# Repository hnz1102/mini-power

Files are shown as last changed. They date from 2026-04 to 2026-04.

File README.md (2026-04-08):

<div align="center">
  <h1><code>Mini Power for Breadboard</code></h1>
  <p>
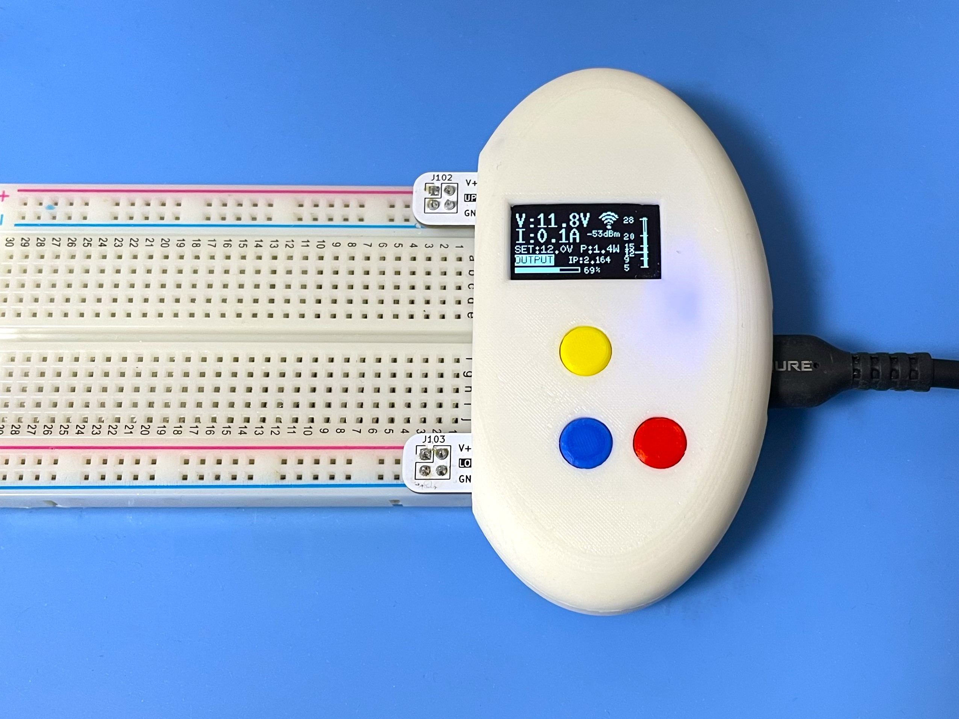
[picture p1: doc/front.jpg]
    
  </p>
</div>

# Mini-Power

Mini-Power is a small, portable DC power supply unit designed to provide a convenient and reliable source of adjustable voltage for your electronic devices and breadboard experiments. Powered from a USB Power Delivery (PD) charger, it supports both Standard Power Range (SPR) and Extended Power Range (EPR) modes, making it perfect for electronics developers, students, and anyone who needs a compact bench power supply.

## Key Features

- **Easy access to the breadboard**: both sides accessible via standard 2.54mm pitch pin headers.
- **USB PD support**: 5V to 28V output using the AP33772S PD Sink Controller.
- **Variable voltage**: 0.1V steps using PPS APDO, with automatic fallback to the nearest Fixed PDO.
- **Real-time display**: SSD1306 128×64 OLED showing output voltage, measured voltage, current, power, WiFi status, and buffer usage.
- **Data logging**: Measurements sent to InfluxDB over WiFi (InfluxDB Line Protocol, HTTPS).
- **Remote syslog**: RFC 5424 over UDP for monitoring and troubleshooting.
- **HTTP web interface**: Real-time graphs (Chart.js), voltage control, and output ON/OFF toggle from any browser on the local network.
- **Three-button interface**: Up / Down / Center push buttons for direct voltage adjustment and output control.
- **NVS persistence**: Last voltage setting is saved to flash and restored on reboot.
- **Safety protections**: OVP, UVP, OCP (in AP33772S hardware) plus software current/power limits and voltage overshoot detection (>110% of setpoint).

## Hardware Components

| Reference | Part | Description |
|---|---|---|
| U103 | ESP32-C3-WROOM-02-N4 | Main microcontroller (RISC-V, built-in WiFi, 4MB flash) |
| U104 | AP33772SDKZ-13-FA01 | USB Power Delivery Sink Controller (SPR + EPR), QFN4040-24 |
| U102 | SSD1306 | Monochrome OLED display (128×64 pixels, I2C) |
| U101 | PCA9306D | Dual bidirectional I2C voltage-level translator (SSOP-8) |
| U105 | NJW1933F1 | Synchronous step-down DC/DC converter for 3.3V supply (SOT-23-6) |
| Q101, Q102 | DMN3008SFG | Dual N-channel MOSFET for output switching (PowerDI3333-8) |
| J101 | USB4105-GF-A | USB Type-C connector (input) |
| J102, J103 | 2×2 pin header | Output terminals (UPPER OUT / LOWER OUT), 2.54mm pitch |
| SW101–SW103 | TS-06104 | Push buttons: Up (GPIO10), Down (GPIO20), Center (GPIO21) |
| R110 | 5mΩ shunt resistor | Current sensing resistor (2512 package) |
| L101 | 22µH | Inductor for DC/DC converter |
| D101 | LED (Blue) | Status indicator |
| D102 | SK36A-LTP | Schottky diode (SMA) |
| FB101 | MH2029-601Y | Ferrite bead for EMI filtering |

Schematic and PCB files are in the `hardware/` directory. The board is designed with [KiCad](https://www.kicad.org/). A PDF export of the schematic is available at [`hardware/schematic.pdf`](hardware/schematic.pdf).

The [ap33772s-driver](https://github.com/hnz1102/ap33772s-driver) crate is used for all USB-PD communication with the AP33772S controller.

## Software Architecture

The firmware is written entirely in Rust using the ESP-IDF framework.

| File | Responsibility |
|---|---|
| `main.rs` | Startup, peripheral init, NVS load/save, main control loop |
| `usbpd.rs` | AP33772S PD driver wrapper (PDO negotiation, custom voltage request, VOUT control) |
| `displayctl.rs` | SSD1306 OLED driver, display thread, PDO list screen |
| `currentlogs.rs` | In-memory ring buffer (up to 127 records) for voltage/current/power/temp data |
| `transfer.rs` | InfluxDB Line Protocol HTTP transfer thread |
| `httpserver.rs` | HTTP server, REST API (`/api/status`, `/api/voltage`, `/api/output`, `/api/pdos`), embedded HTML/JS |
| `keyevent.rs` | GPIO key scanner (10ms polling, 100ms guard time) with long-press detection |
| `wifi.rs` | WiFi connection, RSSI monitoring, automatic reconnect |
| `syslogger.rs` | RFC 5424 UDP syslog, replaces the default ESP console logger |

## How to Use the Unit

### Basic Operation

1. **Connection**: Connect a USB-C PD charger*1 to the input port.
2. **Power On**: The unit negotiates PD profiles and scrolls through the available PDO list on the display.
3. **Main Screen**: After getting a IP address from DHCP server*2, the display shows output voltage, current, power, WiFi RSSI, IP address(last two octets)and buffer usage. 
4. **Voltage Selection**: Press **Up(yellow)** or **Down(blue)** to increase/decrease the target voltage in 0.1V steps.
5. **Output Control**: Press **Center(red)** to toggle output ON/OFF.
6. **Monitoring**: View real-time measurements on the OLED display or open `http://<device-ip>/` in a browser.

**Note** 
*1: When it doesn't connect to the PD charger, the display will show "No PD Power". Click the up/down buttons to show main screen. It only can output 5V.
*2: If it can't connect to WiFi, the display will show the main screen after 30 seconds, but without IP address and RSSI. 

### Button Controls

| Button | GPIO | Function |
|---|---|---|
| Up | GPIO10 | Increase output voltage by 0.1V |
| Down | GPIO20 | Decrease output voltage by 0.1V |
| Center | GPIO21 | Toggle output ON/OFF |

### OLED Display

The SSD1306 128×64 monochrome OLED display is divided into several regions as shown below.

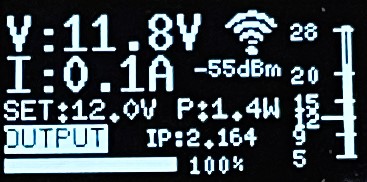
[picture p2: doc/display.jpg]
display layout


| Area | Content | Detail |
|---|---|---|
| `V:xx.xV` | Measured voltage | Read from AP33772S (updated every 100ms when output ON) |
| `I:xx.xA` | Measured current | Read from AP33772S (updated every 100ms when output ON) |
| `SET:xx.xV` | Target output voltage | Blinks while PD voltage negotiation is in progress |
| `P:xx.xW` / `P:xx.xmW` | Measured power | Auto-range: switches between mW and W (threshold 0.5W / 1.0W) |
| `OUTPUT` / `STOPPED` | Output state | `OUTPUT` shown inverted (white on black) when output is ON |
| IP address | Last two octets of device IP | e.g. `IP:2.142` for `192.168.2.142` |
| Buffer bar | InfluxDB send buffer usage | 60px wide bar; fills left-to-right as records accumulate (max 127) |
| `xxx%` | Buffer usage percentage | Displayed to the right of the buffer bar |
| WiFi icon | WiFi signal strength | 5-level icon (wifi-0 to wifi-4) based on RSSI; animated while connecting |
| `+xx dBm` | RSSI value | Shown below WiFi icon when connected |
| Voltage bar (right edge) | PDO voltage range | Vertical bar showing min–max PD voltage; Variable/PPS range filled, Fixed PDO voltages marked as horizontal lines; current SET voltage shown as a longer line marker |

**Startup sequence:**

1. At boot, the PDO list screen is shown first — all Power Data Objects negotiated with the charger are listed (voltage, current, max power, type). Each page is shown for 3 seconds.
2. After PDO display completes, the main screen appears.
3. Error / warning messages (e.g. `Voltage Overshoot`, `Current OV x.xxxA`) replace the main screen temporarily and auto-dismiss after 3 seconds.

### HTTP Web Interface

When connected to WiFi, open `http://<device-ip>/` (IP shown on OLED display) to access:

- Live voltage, current, and power readings updated every second
- Real-time voltage and current graph (Chart.js)
- PDO table showing all available power profiles from the charger
- Voltage control with +/− buttons (0.1V step)
- Output ON/OFF toggle

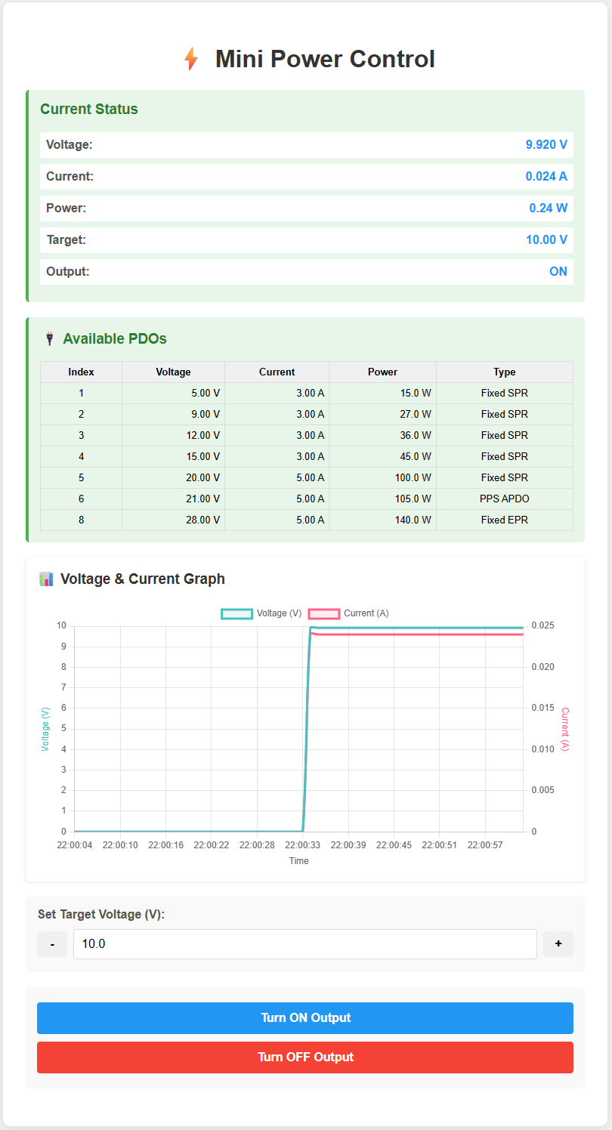
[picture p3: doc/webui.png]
webui


### Safety Protections

| Protection | Mechanism |
|---|---|
| Over Voltage Protection (OVP) | AP33772S hardware |
| Under Voltage Protection (UVP) | AP33772S hardware |
| Over Current Protection (OCP) | AP33772S hardware |
| Software current limit | Output disabled if current exceeds `max_current_limit` |
| Software power limit | Output disabled if power exceeds `max_power_limit` |
| Voltage overshoot detection | Output disabled if measured voltage > 110% of setpoint |

## How to Build from Code and Install to the Unit

### Using Ubuntu 22.04 LTS

**1. Install Rust Compiler**

```bash
sudo apt update && sudo apt -y install git python3 python3-pip gcc build-essential \
  curl pkg-config libudev-dev libtinfo5 clang libclang-dev llvm-dev udev libssl-dev python3.10-venv nano
```
```bash
curl --proto '=https' --tlsv1.2 -sSf https://sh.rustup.rs | sh
# Select option 1 (default install)
```
```bash
source "$HOME/.cargo/env"
```

**2. Install toolchain for ESP32-C3**

```bash
cargo install ldproxy
cargo install cargo-binstall
cargo install espup
espup install
espup update
. ./export-esp.sh
cargo binstall cargo-espflash
```

**3. Add UDEV rules**

```bash
sudo sh -c 'echo "SUBSYSTEMS==\"usb\", ATTRS{idVendor}==\"303a\", ATTRS{idProduct}==\"1001\", MODE=\"0666\"" \
  > /etc/udev/rules.d/99-esp32.rules'
sudo udevadm control --reload-rules
sudo udevadm trigger
```

**4. Clone the repository**

```bash
git clone https://github.com/hnz1102/mini-power.git
cd mini-power/code
```

**5. Configure WiFi and InfluxDB**

```bash
cp cfg.toml.samp cfg.toml
nano cfg.toml
```

```toml
[mini-power]
wifi_ssid = "YOUR_WIFI_SSID"
wifi_psk = "YOUR_WIFI_PASSWORD"
influxdb_server = "192.168.x.x:8086"
influxdb_api_key = "<YOUR_API_KEY>"
influxdb_api = "/api/v2/write?org=<ORG>&bucket=LOGGER&precision=ns"
influxdb_measurement = "minipower"
influxdb_tag = "ch"
max_current_limit = "5.2"
max_power_limit = "100.0"
max_temperature = "75"
syslog_server = "192.168.x.x:514"
syslog_enable = "false"
```

**6. Connect the board and verify**

```bash
cargo espflash board-info
# Select /dev/ttyACM0
# Expected: Chip type: esp32c3, Flash size: 4MB
```

**7. Build and flash**

```bash
cargo espflash flash --release --monitor
```

The device boots automatically after flashing. The OLED display will show the PDO list negotiated with the charger, then switch to the main monitoring screen.

## How to Install InfluxDB and Configure the Dashboard

**1. Download and install InfluxDB**

```bash
wget https://dl.influxdata.com/influxdb/releases/influxdb2-2.7.0-amd64.deb
sudo dpkg -i influxdb2-2.7.0-amd64.deb
sudo service influxdb start
```

**2. Initial configuration**

Open `http://<server-ip>:8086`. Click `GET STARTED` and set:

| Term | Value |
|---|---|
| Username | Admin login username |
| Password | Admin login password |
| Initial Organization Name | e.g. `ORG` |
| Initial Bucket Name | `LOGGER` |

**3. Get the API Token**

Copy the Operator API Token shown after setup — you will not see it again. To generate a new token later: `API Tokens` → `GENERATE API TOKEN` → `All access token`.

**4. Import the Dashboard Template**

Click `Dashboard` → `CREATE DASHBOARD` → `Import Dashboard`. Drop the `influxdb/mimi-power.json` file into the import dialog, then click `IMPORT JSON AS DASHBOARD`.

You will see the **Mimi-POWER** dashboard. It contains three time-series graphs:

| Chart | Field | Unit |
|---|---|---|
| Voltage | `voltage` | V |
| Current | `current` | A |
| Power | `power` | W |

All charts query the `LOGGER` bucket, measurement `minipower`, tag `tag = "ch"`.

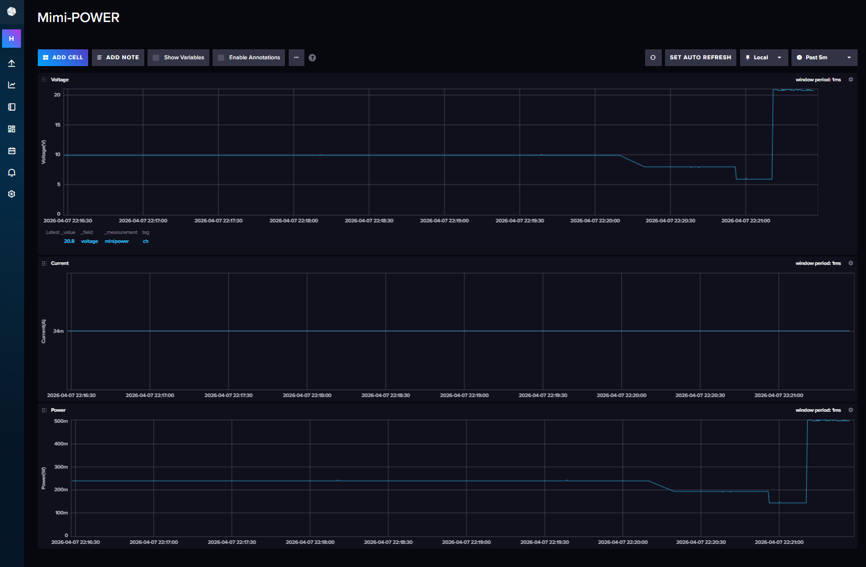
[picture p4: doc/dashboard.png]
dashboard


**5. Start logging**

Enable the output on the Mini-Power unit (Center button or web interface). Measurement data will be sent to InfluxDB and appear on the dashboard in real-time.

## Schematic and PCB Data

The PCB is designed with [KiCad](https://www.kicad.org/). All hardware design files are in the `hardware/` directory.

| File / Directory | Description |
|---|---|
| [`hardware/schematic.pdf`](hardware/schematic.pdf) | Schematic PDF (for viewing without KiCad) |
| `hardware/mini-power.kicad_sch` | KiCad schematic source |
| `hardware/mini-power.kicad_pcb` | KiCad PCB layout |
| `hardware/bom.csv` | Bill of Materials |
| `hardware/production/` | Gerber files for PCB manufacturing (`mini-power.kicad_pcb_gerber.zip`) |

## 3D Printed Enclosure

The enclosure design files are in the `hardware/Container/` directory.

| File | Description |
|---|---|
| `body.3mf` | Main enclosure body |
| `upper.3mf` | Top cover |
| `button.3mf` | Button cap for the three push switches |
| `mini-power.f3d` | Fusion 360 source file |

All parts are designed for FDM 3D printing. Print `body.3mf`, `upper.3mf`, and three copies of `button.3mf`.

## License

This source code is licensed under MIT. Other Hardware Schematic documents are licensed under CC-BY-SA V4.0.

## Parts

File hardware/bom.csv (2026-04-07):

Reference | Qty | Value | DNP | Exclude from BOM | Exclude from Board | Footprint | Datasheet | digikey
C101,C110 | 2 | 1uF |  |  |  | Capacitor_SMD:C_0805_2012Metric | ~ | 311-1365-1-ND
C102,C103,C105,C106,C108 | 5 | 0.1uF/50V |  |  |  | Capacitor_SMD:C_0603_1608Metric | ~ | 311-1343-1-ND
C104,C111 | 2 | 10uF/50V |  |  |  | Capacitor_SMD:C_0805_2012Metric | ~ | 490-18663-1-ND
C107 | 1 | 0.01uF/50V |  |  |  | Capacitor_SMD:C_0603_1608Metric | ~ | 311-1349-1-ND
C109 | 1 | 2.2uF/50V |  |  |  | Capacitor_SMD:C_0603_1608Metric | ~ | 587-4320-1-ND
C112 | 1 | 47uF |  |  |  | Capacitor_SMD:C_0805_2012Metric | ~ | 587-4280-1-ND
D101 | 1 | LED BLUE |  |  |  | LED_SMD:LED_0603_1608Metric | ~ | 3147-B1931NB--20C007614U1930CT-ND
D102 | 1 | SK36A-LTP |  |  |  | Diode_SMD:D_SMA |  | SK36A-LTPMSCT-ND
FB101 | 1 | MH2029-601Y |  |  |  | Inductor_SMD:L_0805_2012Metric | ~ | MH2029-601YCT-ND
J101 | 1 | USB4105-GF-A |  |  |  | Library:USB_C_5077CR-16-SMC2-BK-TR | https://www.usb.org/sites/default/files/documents/usb_type-c.zip | 2073-USB4105-GF-ACT-ND
J102 | 1 | UPPER OUT |  |  |  | Connector_PinHeader_2.54mm:PinHeader_2x02_P2.54mm_Vertical | ~ | 2057-PH2-04-UA-ND
J103 | 1 | LOWER OUT |  |  |  | Connector_PinHeader_2.54mm:PinHeader_2x02_P2.54mm_Vertical | ~ | 2057-PH2-04-UA-ND
JP101 | 1 | SolderJumper_2_Open |  |  |  | Jumper:SolderJumper-2_P1.3mm_Open_RoundedPad1.0x1.5mm | ~ | -
L101 | 1 | 22uH |  |  |  | Library:L_CHPH4D19FNP | ~ | 308-1313-1-ND
Q101,Q102 | 2 | DMN3008SFG |  |  |  | Package_SON:Diodes_PowerDI3333-8 | https://www.diodes.com/assets/Datasheets/DMN3008SFG.pdf | DMN3008SFG-7DICT-ND
R101,R105,R107,R111,R117,R118,R119,R120 | 8 | 10K |  |  |  | Resistor_SMD:R_0603_1608Metric | ~ | 311-10.0KHRCT-ND
R102 | 1 | 200K |  |  |  | Resistor_SMD:R_0603_1608Metric | ~ | 311-200KHRCT-ND
R103,R104,R116 | 3 | 5K1 |  |  |  | Resistor_SMD:R_0603_1608Metric | ~ | 311-5.10KHRCT-ND
R106 | 1 | 1K |  |  |  | Resistor_SMD:R_0603_1608Metric | ~ | RMCF0603FT1K00CT-ND
R108,R109 | 2 | 4.7K |  |  |  | Resistor_SMD:R_0603_1608Metric | ~ | 311-4.70KHRCT-ND
R110 | 1 | 5m |  |  |  | Resistor_SMD:R_2512_6332Metric_Pad1.40x3.35mm_HandSolder | ~ | 4506-PEWF2512D5L00Q9CT-ND
R112 | 1 | 100R |  |  |  | Resistor_SMD:R_0603_1608Metric | ~ | 311-10.0HRCT-ND
R114 | 1 | 100 |  |  |  | Resistor_SMD:R_0603_1608Metric | ~ | 311-100GRCT-ND
R115 | 1 | 3K09 |  |  |  | Resistor_SMD:R_0603_1608Metric | ~ | 311-3.09KHRCT-ND
SW101,SW102,SW103 | 3 | TS-06104 |  |  |  | Library:TS-06104 |  | C2939203 JLPCB Part#
TP101 | 1 | 5V |  |  |  | TestPoint:TestPoint_Pad_D1.0mm | ~ | -
TP102 | 1 | VDD |  |  |  | TestPoint:TestPoint_Pad_D1.0mm | ~ | -
TP103 | 1 | 3V3 |  |  |  | TestPoint:TestPoint_Pad_D1.0mm | ~ | -
U101 | 1 | PCA9306D |  |  |  | Package_SO:SSOP-8_2.95x2.8mm_P0.65mm | https://www.nxp.com/docs/en/data-sheet/PCA9306.pdf | 568-4215-1-ND
U102 | 1 | SSD1306_DISPLAY |  |  |  | Library:OLED I2C DISPLAY |  | https://akizukidenshi.com/catalog/g/g112031/
U103 | 1 | ESP32-C3-WROOM-02-N4 |  |  |  | Library:IC18_ESP32-C3-WROOM-02-N4_EXP | ESP32-C3-WROOM-02-N4 | 1965-ESP32-C3-WROOM-02-N4CT-ND
U104 | 1 | AP33772SDKZ-13-FA01 |  |  |  | Library:W-QFN4040-24_Type_A1_DIO | AP33772SDKZ-13 | 31-AP33772SDKZ-13-FA01CT-ND
U105 | 1 | NJW1933F1 |  |  |  | Package_TO_SOT_SMD:SOT-23-6

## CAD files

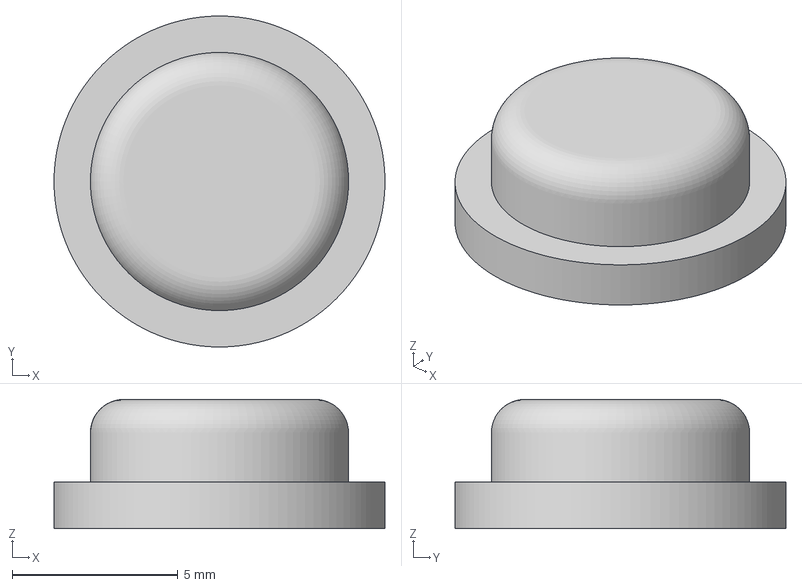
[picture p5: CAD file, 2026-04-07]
hardware/Container/button.3mf
10.0 x 10.0 x 3.90 mm

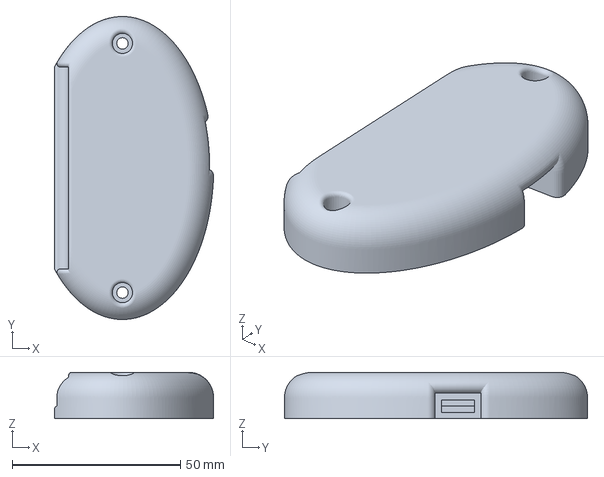
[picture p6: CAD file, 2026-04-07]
hardware/Container/body.3mf
47.3 x 90.0 x 13.8 mm

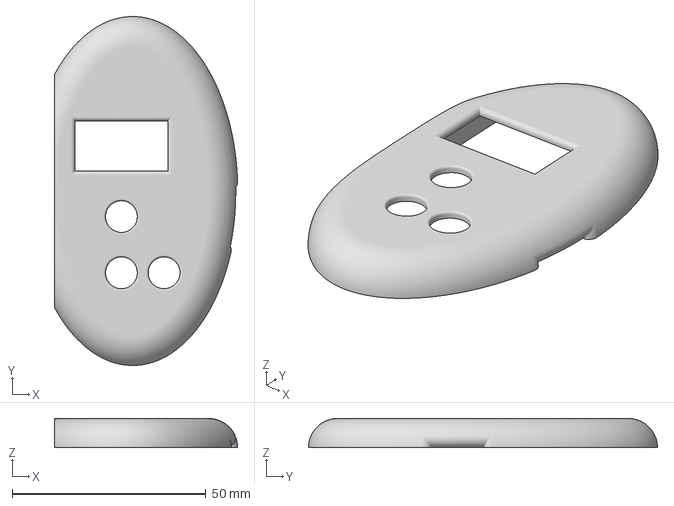
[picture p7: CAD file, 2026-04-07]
hardware/Container/upper.3mf
47.3 x 90.0 x 7.50 mm

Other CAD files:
hardware/Container/mini-power.f3d

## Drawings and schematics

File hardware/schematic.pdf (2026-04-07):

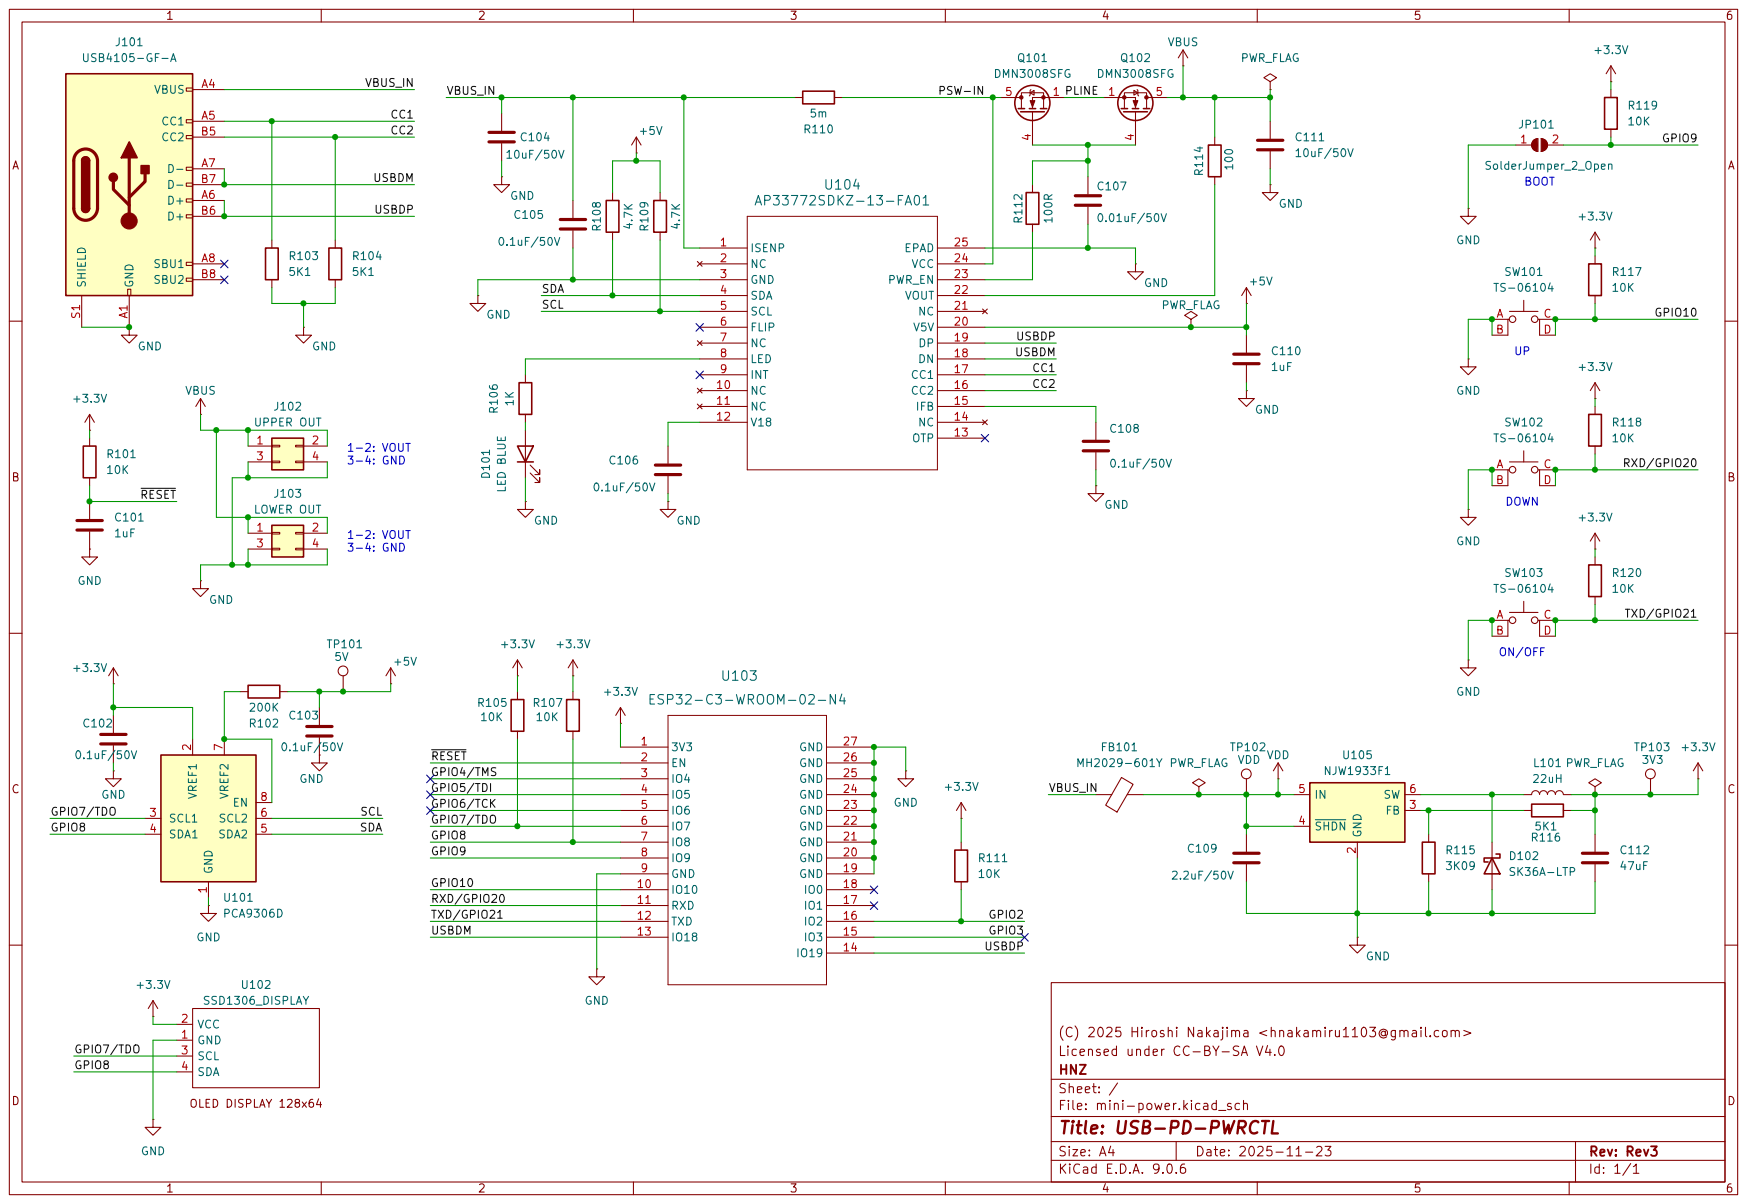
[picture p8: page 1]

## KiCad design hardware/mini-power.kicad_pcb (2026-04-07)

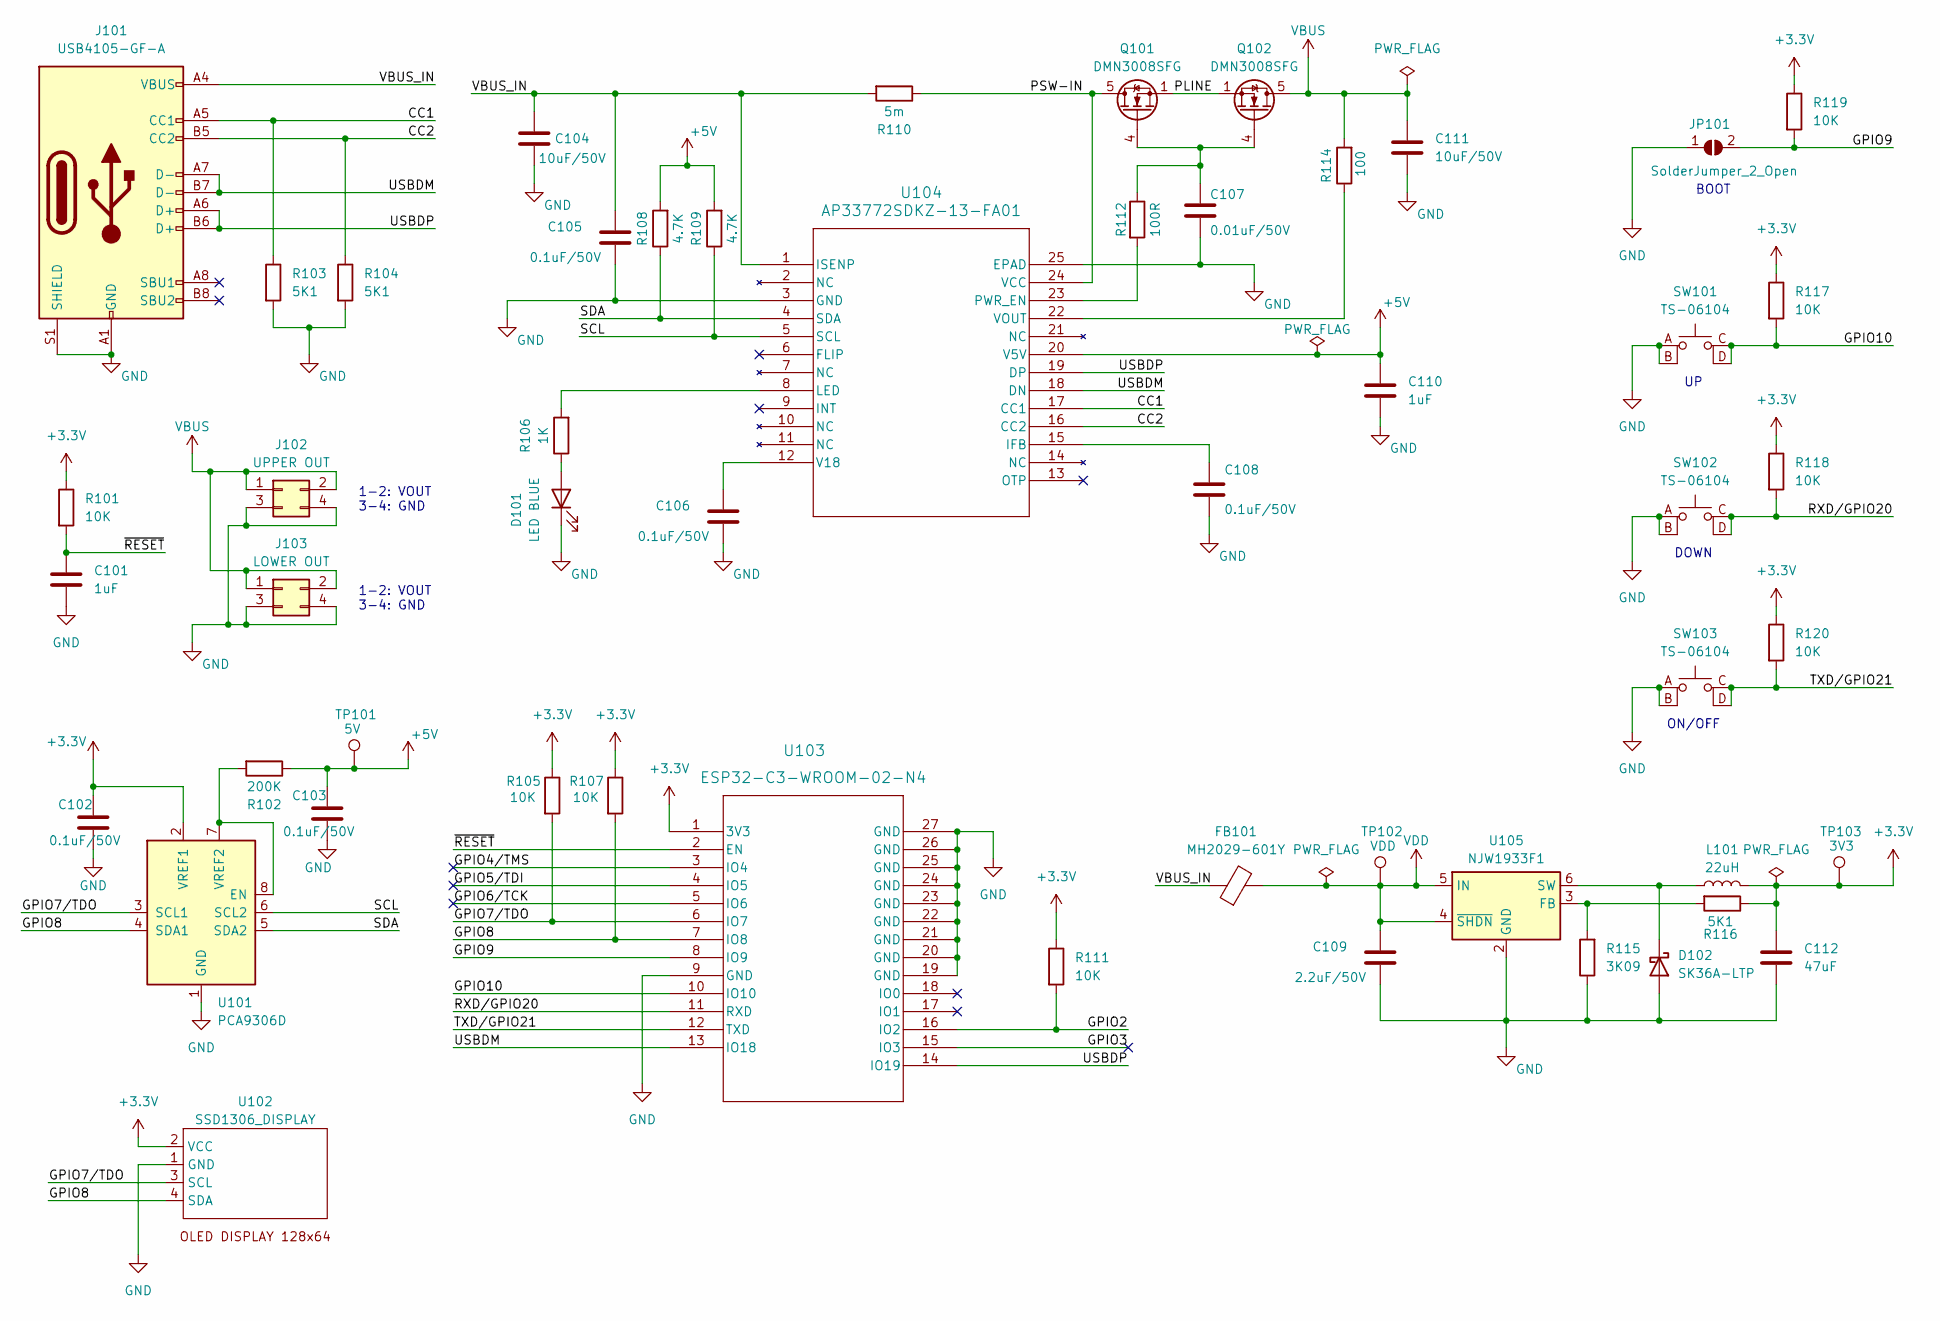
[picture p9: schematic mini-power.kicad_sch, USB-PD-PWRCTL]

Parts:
C101, C110: 1uF; C_0805_2012Metric; digikey 311-1365-1-ND
C102, C103, C105, C106, C108: 0.1uF/50V; C_0603_1608Metric; digikey 311-1343-1-ND
C104, C111: 10uF/50V; C_0805_2012Metric; digikey 490-18663-1-ND
C107: 0.01uF/50V; C_0603_1608Metric; digikey 311-1349-1-ND
C109: 2.2uF/50V; C_0603_1608Metric; digikey 587-4320-1-ND
C112: 47uF; C_0805_2012Metric; digikey 587-4280-1-ND
D101: LED BLUE; LED_0603_1608Metric; digikey 3147-B1931NB--20C007614U1930CT-ND
D102: SK36A-LTP; D_SMA; digikey SK36A-LTPMSCT-ND
FB101: MH2029-601Y; L_0805_2012Metric; digikey MH2029-601YCT-ND
J101: USB4105-GF-A; USB_C_5077CR-16-SMC2-BK-TR; digikey 2073-USB4105-GF-ACT-ND
J102: UPPER OUT; PinHeader_2x02_P2.54mm_Vertical; digikey 2057-PH2-04-UA-ND
J103: LOWER OUT; PinHeader_2x02_P2.54mm_Vertical; digikey 2057-PH2-04-UA-ND
JP101: SolderJumper_2_Open; SolderJumper-2_P1.3mm_Open_RoundedPad1.0x1.5mm
L101: 22uH; L_CHPH4D19FNP; digikey 308-1313-1-ND
Q101, Q102: DMN3008SFG; Diodes_PowerDI3333-8; digikey DMN3008SFG-7DICT-ND
R101, R105, R107, R111, R117, R118, R119, R120: 10K; R_0603_1608Metric; digikey 311-10.0KHRCT-ND
R102: 200K; R_0603_1608Metric; digikey 311-200KHRCT-ND
R103, R104, R116: 5K1; R_0603_1608Metric; digikey 311-5.10KHRCT-ND
R106: 1K; R_0603_1608Metric; digikey RMCF0603FT1K00CT-ND
R108, R109: 4.7K; R_0603_1608Metric; digikey 311-4.70KHRCT-ND
R110: 5m; R_2512_6332Metric_Pad1.40x3.35mm_HandSolder; digikey 4506-PEWF2512D5L00Q9CT-ND
R112: 100R; R_0603_1608Metric; digikey 311-10.0HRCT-ND
R114: 100; R_0603_1608Metric; digikey 311-100GRCT-ND
R115: 3K09; R_0603_1608Metric; digikey 311-3.09KHRCT-ND
SW101, SW102, SW103: TS-06104; digikey C2939203 JLPCB Part#
TP101: 5V; TestPoint_Pad_D1.0mm
TP102: VDD; TestPoint_Pad_D1.0mm
TP103: 3V3; TestPoint_Pad_D1.0mm
U101: PCA9306D; SSOP-8_2.95x2.8mm_P0.65mm; digikey 568-4215-1-ND
U102: SSD1306_DISPLAY; OLED I2C DISPLAY
U103: ESP32-C3-WROOM-02-N4; IC18_ESP32-C3-WROOM-02-N4_EXP; digikey 1965-ESP32-C3-WROOM-02-N4CT-ND
U104: AP33772SDKZ-13-FA01; W-QFN4040-24_Type_A1_DIO; digikey 31-AP33772SDKZ-13-FA01CT-ND
U105: NJW1933F1; SOT-23-6

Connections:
+3.3V: C102.1, C112.1, L101.2, R101.1, R105.1, R107.1, R111.1, R116.1, R117.1, R118.1, R119.1, R120.1, TP103.1, U101.2 (VREF1), U102.2 (VCC), U103.1 (3V3)
+5V: C103.1, C110.1, R102.1, R108.2, R109.2, TP101.1, U104.20 (V5V)
/CC1: J101.A5 (CC1), R103.1, U104.17 (CC1)
/CC2: J101.B5 (CC2), R104.1, U104.16 (CC2)
/GPIO2: R111.2, U103.16 (IO2)
/GPIO3: U103.15 (IO3)
/GPIO4/TMS: U103.3 (IO4)
/GPIO5/TDI: U103.4 (IO5)
/GPIO6/TCK: U103.5 (IO6)
/GPIO7/TDO: R105.2, U101.3 (SCL1), U102.3 (SCL), U103.6 (IO7)
/GPIO8: R107.2, U101.4 (SDA1), U102.4 (SDA), U103.7 (IO8)
/GPIO9: JP101.2 (B), R119.2, U103.8 (IO9)
/GPIO10: R117.2, SW101.C, SW101.D, U103.10 (IO10)
/PLINE: Q101.1 (S), Q101.2 (S), Q101.3 (S), Q102.1 (S), Q102.2 (S), Q102.3 (S)
/PSW-IN: Q101.5 (D), R110.1, U104.24 (VCC)
/RXD/GPIO20: R118.2, SW102.C, SW102.D, U103.11 (RXD)
/SCL: R109.1, U101.6 (SCL2), U104.5 (SCL)
/SDA: R108.1, U101.5 (SDA2), U104.4 (SDA)
/TXD/GPIO21: R120.2, SW103.C, SW103.D, U103.12 (TXD)
/USBDM: J101.A7 (D-), J101.B7 (D-), U103.13 (IO18), U104.18 (DN)
/USBDP: J101.A6 (D+), J101.B6 (D+), U103.14 (IO19), U104.19 (DP)
/VBUS_IN: C104.1, C105.1, FB101.1, J101.A4 (VBUS), J101.A9 (VBUS), J101.B4 (VBUS), J101.B9 (VBUS), R110.2, U104.1 (ISENP)
/~RESET: C101.1, R101.2, U103.2 (EN)
GND: C101.2, C102.2, C103.2, C104.2, C105.2, C106.2, C107.2, C108.2, C109.2, C110.2, C111.2, C112.2, D101.1 (K), D102.2 (A), J101.A1 (GND), J101.A12 (GND), J101.B1 (GND), J101.B12 (GND), J101.S1 (SHIELD), J102.3, J102.4, J103.3, J103.4, JP101.1 (A), R103.2, R104.2, R115.1, SW101.A, SW101.B, SW102.A, SW102.B, SW103.A, SW103.B, U101.1 (GND), U102.1 (GND), U103.9 (GND), U103.19 (GND), U103.20 (GND), U103.21 (GND), U103.22 (GND), U103.23 (GND), U103.24 (GND), U103.25 (GND), U103.26 (GND), U103.27 (GND), U104.3 (GND), U104.25 (EPAD), U105.2 (GND)
unnamed: D101.2 (A), R106.1
unnamed: D102.1 (K), L101.1, U105.6 (SW)
unnamed: C107.1, Q101.4 (G), Q102.4 (G), R112.1
unnamed: R102.2, U101.7 (VREF2), U101.8 (EN)
unnamed: C108.1, U104.15 (IFB)
unnamed: R106.2, U104.8 (LED)
unnamed: R112.2, U104.23 (PWR_EN)
unnamed: C106.1, U104.12 (V18)
unnamed: R114.1, U104.22 (VOUT)
unnamed: R115.2, R116.2, U105.3 (FB)
VBUS: C111.1, J102.1, J102.2, J103.1, J103.2, Q102.5 (D), R114.2
VDD: C109.1, FB101.2, TP102.1, U105.4 (~SHDN), U105.5 (IN)

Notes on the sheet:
DOWN
1-2: VOUT 3-4: GND
ON/OFF
BOOT

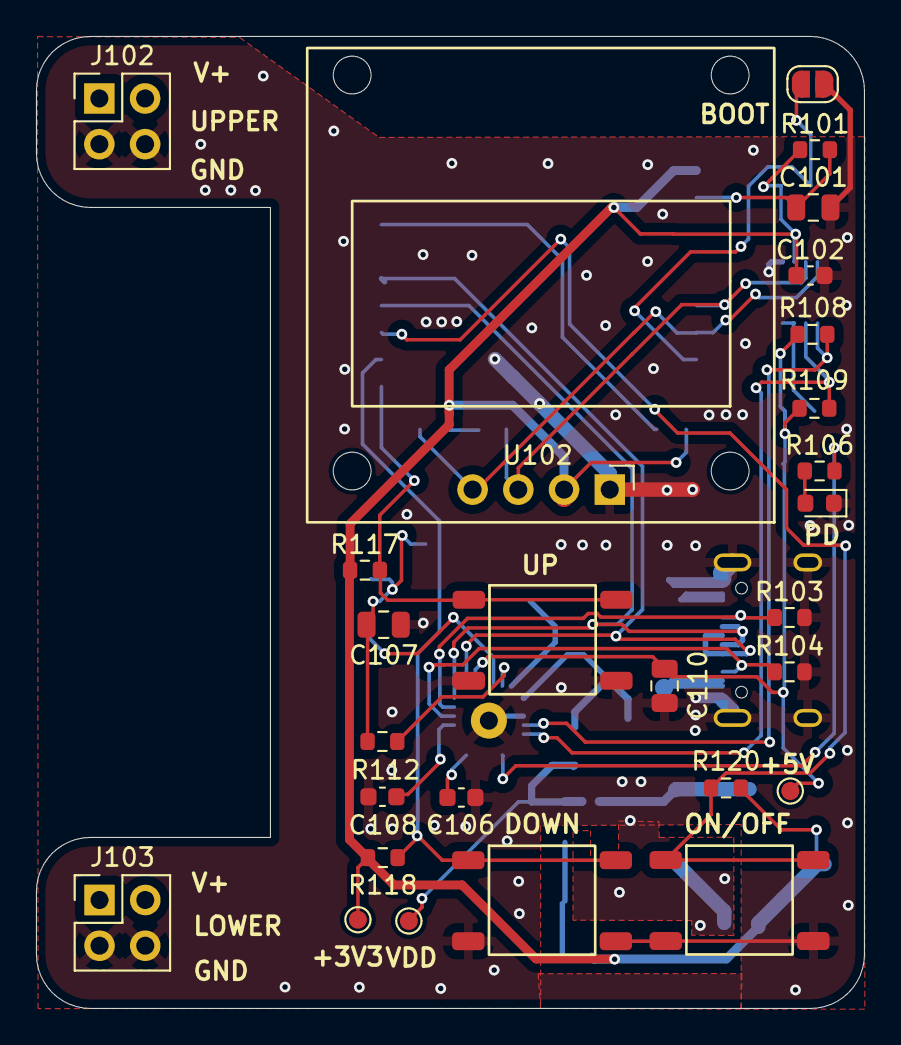
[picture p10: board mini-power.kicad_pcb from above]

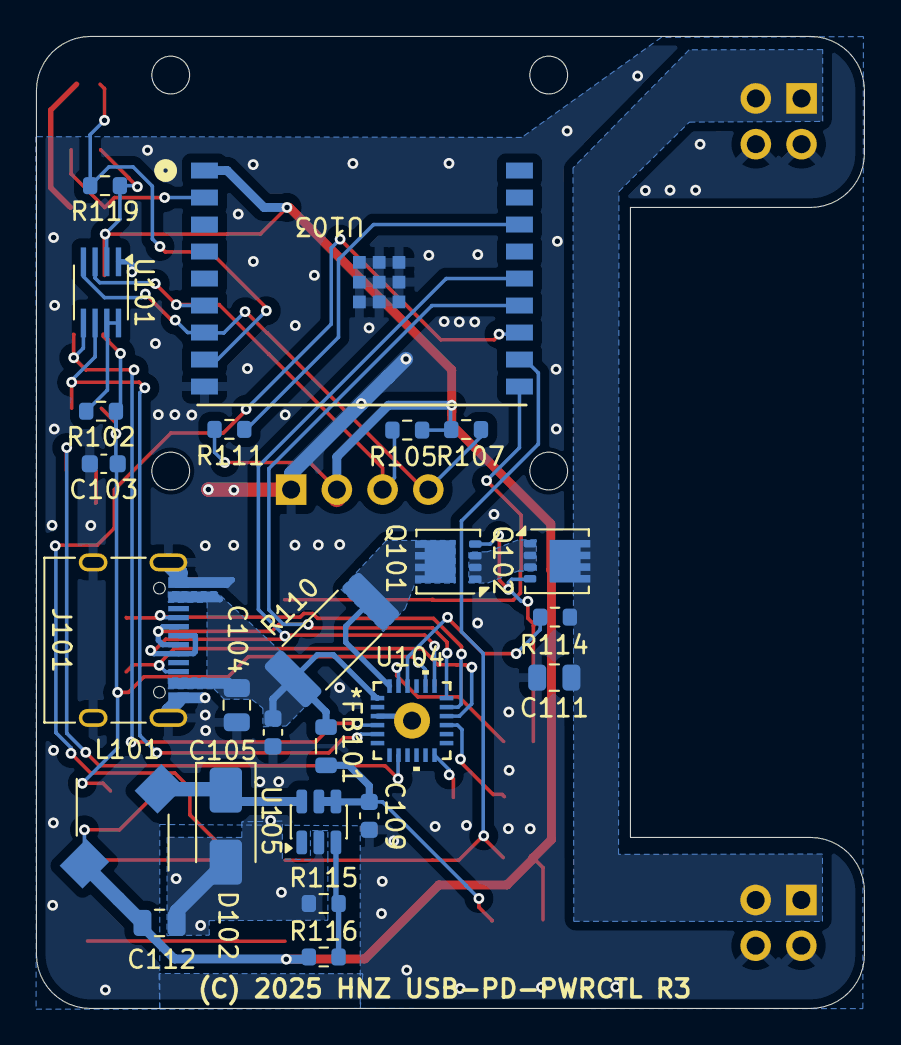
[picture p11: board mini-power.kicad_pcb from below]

Board: 2 copper layers, 46.0 x 54.0 mm, 52 parts (25 on the bottom side), 32 nets.

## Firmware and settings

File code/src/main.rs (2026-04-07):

// This is mini-power main program for ESP32-C3-WROOM.
// SPDX-License-Identifier: MIT
// Copyright (c) 2025-2026 Hiroshi Nakajima

use std::{thread, time::Duration};
use esp_idf_hal::{gpio::*, prelude::*, i2c};
use esp_idf_hal::peripherals::Peripherals;
use log::*;
use std::time::SystemTime;
use esp_idf_svc::sntp::{EspSntp, SyncStatus, SntpConf, OperatingMode, SyncMode};
use esp_idf_svc::wifi::EspWifi;
use esp_idf_svc::nvs::*;
use chrono::{DateTime, Utc};

mod displayctl;
mod currentlogs;
mod wifi;
mod transfer;
mod usbpd;
mod syslogger;  // Add the syslogger module
mod keyevent;
mod httpserver;

use displayctl::{DisplayPanel, LoggingStatus, WifiStatus};
use currentlogs::{CurrentRecord, CurrentLog};
use transfer::{Transfer, ServerInfo};
use usbpd::{AP33772S, PDVoltage};
use keyevent::{KeySwitch, KeyEvent};
use httpserver::PowerControlState;

#[toml_cfg::toml_config]
pub struct Config {
    #[default("")]
    wifi_ssid: &'static str,
    #[default("")]
    wifi_psk: &'static str,
    #[default("")]
    influxdb_server: &'static str,
    #[default("11.0")]
    max_current_limit: &'static str,
    #[default("110.0")]
    max_power_limit: &'static str,
    #[default("75.0")]
    max_temperature: &'static str,
    #[default("")]
    influxdb_api_key: &'static str,
    #[default("")]
    influxdb_api: &'static str,
    #[default("")]
    influxdb_measurement: &'static str,
    #[default("")]
    influxdb_tag: &'static str,
    #[default("")]
    syslog_server: &'static str,
    #[default("")]
    syslog_enable: &'static str,
}

// NVS key for storing the last voltage setting
const NVS_NAMESPACE: &str = "mini_power_unit";
const VOLTAGE_KEY: &str = "last_voltage";

const RECORD_MAX: usize = 127;

// Function to save voltage setting to NVS
fn save_voltage_to_nvs(voltage: f32) -> anyhow::Result<()> {
    let nvs_default_partition = EspDefaultNvsPartition::take()?;
    let mut nvs = EspNvs::new(nvs_default_partition, NVS_NAMESPACE, true)?;
    
    // Convert f32 to bytes for storage
    let voltage_bytes = voltage.to_le_bytes();
    nvs.set_blob(VOLTAGE_KEY, &voltage_bytes)?;
    info!("Voltage {:.3}V saved to NVS", voltage);
    Ok(())
}

// Function to load voltage setting from NVS
fn load_voltage_from_nvs() -> anyhow::Result<f32> {
    let nvs_default_partition = EspDefaultNvsPartition::take()?;
    let nvs = EspNvs::new(nvs_default_partition, NVS_NAMESPACE, false)?;
    
    let mut voltage_bytes = [0u8; 4];
    match nvs.get_blob(VOLTAGE_KEY, &mut voltage_bytes) {
        Ok(Some(_)) => {
            let voltage = f32::from_le_bytes(voltage_bytes);
            info!("Voltage {:.3}V loaded from NVS", voltage);
            Ok(voltage)
        },
        Ok(None) => {
            info!("No voltage setting found in NVS, using default 0.0V");
            Ok(0.0)
        },
        Err(e) => {
            info!("Failed to read voltage from NVS: {:?}, using default 0.0V", e);
            Ok(0.0)
        }
    }
}

fn main() -> anyhow::Result<()> {
    esp_idf_sys::link_patches();
    
    // Initialize the default ESP logger only if syslog is disabled
    // If syslog is enabled, we'll initialize the syslog logger later
    if CONFIG.syslog_enable != "true" {
        esp_idf_svc::log::EspLogger::initialize_default();
        // Set log level to INFO to ensure info!() messages are displayed
        log::set_max_level(log::LevelFilter::Info);
    }
    
    // Peripherals Initialize
    let peripherals = Peripherals::take().unwrap();
    // Initialize nvs
    unsafe {
        esp_idf_sys::nvs_flash_init();
    }

    // Log startup message
    println!("MiniPowerUnit application started (println)");
    info!("MiniPowerUnit application started (info)");
    
    let max_power_limit = CONFIG.max_power_limit.parse::<f32>().unwrap();
    let max_temperature = CONFIG.max_temperature.parse::<f32>().unwrap();
    let max_current_limit = CONFIG.max_current_limit.parse::<f32>().unwrap();
    println!("[Config Limit] Current: {}A  Power: {}W  Temperature: {}°C", max_current_limit, max_power_limit, max_temperature);
    info!("[Config Limit] Current: {}A  Power: {}W  Temperature: {}°C", max_current_limit, max_power_limit, max_temperature);
    let server_info = ServerInfo::new(CONFIG.influxdb_server.to_string(), 
        CONFIG.influxdb_api_key.to_string(),
        CONFIG.influxdb_api.to_string(),
        CONFIG.influxdb_measurement.to_string(),
        CONFIG.influxdb_tag.to_string());

    // GPIO21 as output for enabling AP33772S
    // let mut ap_enable_pin = PinDriver::output(peripherals.pins.gpio21)?;
    // ap_enable_pin.set_low()?; // Disable AP33772S

    // Current/Voltage
    let i2c = peripherals.i2c0;
    let scl = peripherals.pins.gpio7;
    let sda = peripherals.pins.gpio8;
    let config = i2c::I2cConfig::new().baudrate(100.kHz().into());
    let i2c_driver = i2c::I2cDriver::new(i2c, sda, scl, &config)?;

    // Clone the I2C driver for shared use (using Arc and Mutex for thread safety)
    use std::sync::{Arc, Mutex};
    let shared_i2c = Arc::new(Mutex::new(i2c_driver));
    
    // Create display with shared I2C
    let mut dp = DisplayPanel::new();
    let display_i2c = shared_i2c.clone();
    dp.start(display_i2c);

    // Use the shared I2C for INA sensor
    let ap33772s_i2c = shared_i2c.clone();

    // read config
    let mut ap33772s = AP33772S::new();
    {
        let mut i2c_driver = ap33772s_i2c.lock().unwrap();
        match ap33772s.init(&mut *i2c_driver) {
            Ok(()) => {
                info!("AP33772S initialized successfully");
            },
            Err(e) => {
                return Err(anyhow::anyhow!("Failed to initialize AP33772S: {:?}", e));
            }
        }

        // Configure protection features: UVP=true, OVP=true, OCP=true, OTP=false, DR=false
        match ap33772s.configure_protections(&mut *i2c_driver, true, true, true, false, false) {
            Ok(()) => {
                info!("AP33772S protections configured successfully");
            },
            Err(e) => {
                warn!("Failed to configure AP33772S protections: {:?}", e);
            }
        }
        match ap33772s.get_status(&mut *i2c_driver) {
            Ok(status) => {
                // For debugging purposes, log status occasionally
                // Not implemented: NTC thermistor
                info!(
                    "PD Status: Voltage={}mV, Current={}mA, Temp={}°C, PDP={}W",
                    status.voltage_mv,
                    status.current_ma,
                    status.temperature,
                    status.pdp_limit_w
                );
            },
            Err(e) => {
                info!("Failed to read AP33772S status: {:?}", e);
            }
        }
        let _ = ap33772s.request_voltage(&mut *i2c_driver, PDVoltage::V5);
        ap33772s.force_vout_off(&mut *i2c_driver).unwrap();
    }

    // Get PDO limits from connected source
    let pdo_min_voltage = 5.0;
    info!("PDO Min Voltage = {:.2}V", pdo_min_voltage);
    let (mut pdo_max_voltage, pdo_max_current) = ap33772s.get_pdo_limits();
    info!("PDO Limits: Max Voltage = {:.2}V, Max Current = {:.3}A", pdo_max_voltage, pdo_max_current);
    
    // Display PDO list on screen (each page for 5 seconds)
    let pdo_list = ap33772s.get_pdo_list();
    if pdo_list.len() > 0 {
        DisplayPanel::show_pdo_list(shared_i2c.clone(), pdo_list);
        info!("PDO display complete, resuming normal operation");
        
        // Set PDO range information for the voltage bar display
        let pdo_display_list: Vec<displayctl::PDODisplayInfo> = pdo_list.iter().map(|pdo| {
            displayctl::PDODisplayInfo {
                voltage_mv: pdo.voltage_mv,
                is_fixed: pdo.is_fixed,
            }
        }).collect();
        dp.set_pdo_range(pdo_display_list, pdo_min_voltage, pdo_max_voltage);
    }
    
    // Apply the more restrictive limit between config and PDO
    let mut effective_max_current = if pdo_max_current < max_current_limit { pdo_max_current } else { max_current_limit };
    info!("Effective Current Limit: {:.3}A (Config: {:.3}A, PDO: {:.3}A)", 
          effective_max_current, max_current_limit, pdo_max_current);
    println!("[Effective Limits] Voltage: {:.2}V  Current: {:.3}A", pdo_max_voltage, effective_max_current);
    if pdo_max_voltage <= 0.0 {
        info!("Warning: Connected source is not PD powered.");
        dp.set_message("Warning: No PD Power".to_string(), true, 0);
        pdo_max_voltage = 5.0; // Set a default voltage to allow operation
        effective_max_current = 3.0; // Set a default current limit
    }

    // Temperature Logs
    let mut clogs = CurrentRecord::new();

    // Initialize logging for early debugging
    let mut wifi_enable : bool;
    let mut wifi_dev = wifi::wifi_connect(peripherals.modem, CONFIG.wifi_ssid, CONFIG.wifi_psk);

    if CONFIG.syslog_enable == "true" {
        // Initialize syslog logger to replace the default ESP logger
        println!("Initializing syslog logger...");
        thread::sleep(Duration::from_secs(5));
        
        match syslogger::init_logger(CONFIG.syslog_server, CONFIG.syslog_enable) {
            Ok(_) => {
                // Set log level for syslog
                log::set_max_level(log::LevelFilter::Info);
                println!("Syslog logger initialized successfully");
                info!("Syslog logger initialized successfully");
            },
            Err(e) => {
                // Fallback to ESP logger if syslog fails
                println!("Failed to initialize syslog logger: {:?}, using ESP logger instead", e);
                esp_idf_svc::log::EspLogger::initialize_default();
                log::set_max_level(log::LevelFilter::Info);
                info!("Failed to initialize syslog logger: {:?}, using ESP logger instead", e);
            }
        }
    } else {
        // syslog_enable is false, continue using default ESP console logger
        info!("Using default ESP console logger (syslog disabled)");
    }
    
    // NTP Server
    let sntp_conf = SntpConf {
        servers: ["time.aws.com",
                    "time.google.com",
                    "time.cloudflare.com",
                    "ntp.nict.jp"],
        operating_mode: OperatingMode::Poll,
        sync_mode: SyncMode::Immediate,
    };
    let ntp = EspSntp::new(&sntp_conf).unwrap();

    // NTP Sync
    // let now = SystemTime::now();
    // if now.duration_since(UNIX_EPOCH).unwrap().as_millis() < 1700000000 {
    info!("NTP Sync Start..");

    // wait for sync
    let mut sync_count = 0;
    while ntp.get_sync_status() != SyncStatus::Completed {
        sync_count += 1;
        if sync_count > 1000 {
            info!("NTP Sync Timeout");
            break;
        }
        thread::sleep(Duration::from_millis(10));
    }
    let now = SystemTime::now();
    let dt_now : DateTime<Utc> = now.into();
    let formatted = format!("{}", dt_now.format("%Y-%m-%d %H:%M:%S"));
    info!("NTP Sync Completed: {}", formatted);
    
    // Get and display IP address
    if let Ok(ref wifi) = wifi_dev {
        if let Ok(ip_info) = wifi.sta_netif().get_ip_info() {
            let ip_str = format!("{}", ip_info.ip);
            info!("IP Address: {}", ip_str);
            dp.set_ip_address(ip_str);
        }
    }
    
    // Create HTTP server state
    let http_state = PowerControlState::new(pdo_min_voltage, pdo_max_voltage);
    
    // Set PDO list in HTTP state
    {
        let pdo_list = ap33772s.get_pdo_list();
        let pdo_simple_list: Vec<httpserver::PDOInfoSimple> = pdo_list.iter().map(|pdo| {
            httpserver::PDOInfoSimple {
                pdo_index: pdo.pdo_index,
                voltage_mv: pdo.voltage_mv,
                current_ma: pdo.current_ma,
                max_power_mw: pdo.max_power_mw,
                is_fixed: pdo.is_fixed,
            }
        }).collect();
        http_state.set_pdo_list(pdo_simple_list);
        info!("PDO list set in HTTP state: {} PDOs", pdo_list.len());
    }
    
    // Start HTTP server
    let _http_server = match httpserver::start_http_server(http_state.clone()) {
        Ok(server) => {
            info!("HTTP server started successfully");
            Some(server)
        },
        Err(e) => {
            info!("Failed to start HTTP server: {:?}", e);
            None
        }
    };
        
    let mut txd =  Transfer::new(server_info);
    txd.start()?;

    // Key Event Handler
    let mut keyswitch = KeySwitch::new();
    let gpio_up = Box::new(PinDriver::input(peripherals.pins.gpio10)?);
    let gpio_down = Box::new(PinDriver::input(peripherals.pins.gpio20)?);
    let gpio_center = Box::new(PinDriver::input(peripherals.pins.gpio21)?);
    keyswitch.start(gpio_up, gpio_down, gpio_center);
    
    // loop
    let mut measurement_count : u32 = 0;
    let mut logging_start: bool = false;
    let mut load_start = false;
    let mut previous_load_start = false;
    
    // Load last voltage setting from NVS
    let mut set_output_voltage = match load_voltage_from_nvs() {
        Ok(voltage) => {
            // Ensure voltage is within PDO limits
            if voltage > pdo_max_voltage {
                info!("Loaded voltage {:.3}V exceeds PDO limit {:.3}V, using limit", voltage, pdo_max_voltage);
                pdo_max_voltage
            } else if voltage < pdo_min_voltage {
                info!("Loaded voltage {:.3}V below PDO min limit {:.3}V, using min limit", voltage, pdo_min_voltage);
                pdo_min_voltage
            } else {
                voltage
            }
        },
        Err(e) => {
            info!("Failed to load voltage from NVS: {:?}, using 0.0V", e);
            pdo_min_voltage
        }
    };

    // get calibration offset when this starts
    let calibration_offset_voltage: f32 = 0.0;
    let calibration_offset_current: f32 = 0.0;
    // {
    //     let mut i2c_driver = ap33772s_i2c.lock().unwrap();
    //     match ap33772s.get_status(&mut *i2c_driver) {
    //         Ok(status) => {
    //             // calibration_offset_voltage = status.voltage_mv as f32;
    //             calibration_offset_current = status.current_ma as f32;
    //             info!("Calibration offset determined: {}mV, {}mA", calibration_offset_voltage, calibration_offset_current);
    //         },
    //         Err(e) => {
    //             info!("Failed to read AP33772S status for calibration: {:?}, assuming 0.0V offset", e);
    //             calibration_offset_voltage = 0.0;
    //             calibration_offset_current = 0.0;
    //         }
    //     }
    // }


    info!("Initial voltage setting: {:.3}V", set_output_voltage);
    let mut previous_set_output_voltage = set_output_voltage;
    let mut confirmed_set_voltage = set_output_voltage;
    let mut last_set_output_voltage = SystemTime::now();
    // Set initial voltage display
    dp.set_output_voltage(set_output_voltage);
    // Initialize HTTP state with NVS-loaded target so web UI shows saved value
    http_state.set_target_voltage(set_output_voltage);
    http_state.set_output_enabled(load_start);
    loop {
        thread::sleep(Duration::from_millis(100));
        measurement_count += 1;
        
        // Check HTTP server state and apply changes
        let http_target_voltage = http_state.get_target_voltage();
        let http_output_enabled = http_state.get_output_enabled();
        
        // // Debug log to check http_target_voltage updates
        // if measurement_count % 50 == 0 { // Every 5 seconds
        //     info!("Debug: http_target_voltage={:.3}V, set_output_voltage={:.3}V, diff={:.3}V", 
        //           http_target_voltage, set_output_voltage, (http_target_voltage - set_output_voltage).abs());
        // }
        
        // If HTTP server changed the target voltage, update it
        if (http_target_voltage - set_output_voltage).abs() > 0.05 {
            set_output_voltage = http_target_voltage;
            last_set_output_voltage = SystemTime::now();
            dp.set_output_voltage(set_output_voltage);
            info!("HTTP: Voltage changed to {:.2}V", set_output_voltage);
        }
        
        // If HTTP server changed the output state, update it
        if http_output_enabled != load_start {
            load_start = http_output_enabled;
            info!("HTTP: Output {} via web interface", if load_start { "enabled" } else { "disabled" });
        }
        
        // get key event
        let key_event = keyswitch.get_key_event_and_clear();
        if key_event.is_empty() == false {
            dp.set_message("".to_string(), false, 0);
        }
        for event in key_event {
            match event {
                KeyEvent::UpKeyDown => {
                    set_output_voltage += 0.1;
                    if set_output_voltage > pdo_max_voltage {
                        set_output_voltage = pdo_max_voltage;
                    }
                    last_set_output_voltage = SystemTime::now();
                    dp.set_output_voltage(set_output_voltage);
                    http_state.set_target_voltage(set_output_voltage);
                },
                KeyEvent::DownKeyDown => {
                    set_output_voltage -= 0.1;
                    if set_output_voltage < pdo_min_voltage {
                        set_output_voltage = pdo_min_voltage;
                    }
                    last_set_output_voltage = SystemTime::now();
                    dp.set_output_voltage(set_output_voltage);
                    http_state.set_target_voltage(set_output_voltage);
                },
                KeyEvent::CenterKeyDown => {
                    // Toggle load_start when Center key is pressed
                    load_start = !load_start;
                    http_state.set_output_enabled(load_start);
                    info!("Center key pressed! load_start toggled to: {}", load_start);
                },
                KeyEvent::UpDownLongPress => {
                },
                _ => {},
            }
        }

        let rssi = wifi::get_rssi();
        if rssi == 0 {
            wifi_enable = false;
            if measurement_count % 100 == 0 {
                wifi_reconnect(&mut wifi_dev.as_mut().unwrap());
            }
        }
        else {
            wifi_enable = true;
        }

        if wifi_enable == false {
            dp.set_wifi_status(WifiStatus::Disconnected);
        }
        else {
            dp.set_wifi_rssi(rssi);
            dp.set_wifi_status(WifiStatus::Connected);
        }

        // Normal mode: load_start controls the output as before
        if load_start == true {
            // pid.set_setpoint(set_output_voltage);
            let diff_setpoint = set_output_voltage - previous_set_output_voltage;
            if (diff_setpoint.abs() >= 0.05 && last_set_output_voltage.elapsed().unwrap().as_secs() >= 3) || (previous_load_start == false)  {
                // Set USB PD Voltage
                confirmed_set_voltage = set_output_voltage;
                info!("Changing USB PD Voltage to {:.2}V from {:.2}V", set_output_voltage, previous_set_output_voltage);
                dp.set_output_voltage_changing(true);
                {
                    let mut i2c_driver = ap33772s_i2c.lock().unwrap();
                    let actual_voltage = match usbpd_control(&mut ap33772s, &mut *i2c_driver, set_output_voltage, 0.0) {
                        Ok(v) => {
                            info!("USB PD Voltage set to {:.2}V successfully (requested: {:.2}V)", v, set_output_voltage);
                            v
                        },
                        Err(e) => {
                            info!("Failed to set USB PD Voltage to {:.2}V: {:?}", set_output_voltage, e);
                            dp.set_message("Failed to set Voltage".to_string(), true, 3000);
                            load_start = false;
                            http_state.set_output_enabled(false);
                            continue;
                        }
                    };
                    
                    // Update set_output_voltage with actual voltage (for Fixed PDO fallback)
                    if (actual_voltage - set_output_voltage).abs() > 0.05 {
                        info!("Voltage fallback: requested {:.2}V, using Fixed PDO {:.2}V", set_output_voltage, actual_voltage);
                        set_output_voltage = actual_voltage;
                        http_state.set_target_voltage(set_output_voltage);
                        confirmed_set_voltage = set_output_voltage;
                    }
                }
                dp.set_output_voltage(set_output_voltage);
                
                previous_set_output_voltage = set_output_voltage;
                if let Err(e) = save_voltage_to_nvs(set_output_voltage) {
                    info!("Failed to save voltage to NVS: {:?}", e);
                }
                if previous_load_start == false {
                    let mut i2c_driver = ap33772s_i2c.lock().unwrap();
                    ap33772s.force_vout_on(&mut *i2c_driver).unwrap();
                    // ap_enable_pin.set_high().unwrap(); // Enable Output
                    info!("Load started, applying voltage {:.2}V", set_output_voltage);
                    logging_start = true;
                }
                previous_load_start = load_start;
            }
            dp.set_current_status(LoggingStatus::Start);
            }
        else {
            logging_start = false;
            if previous_load_start == true {
                let mut i2c_driver = ap33772s_i2c.lock().unwrap();
                ap33772s.force_vout_off(&mut *i2c_driver).unwrap();
                // ap_enable_pin.set_low()?; // Disable Output
                info!("Load stopped.");
            }
            previous_load_start = load_start;
            dp.set_current_status(LoggingStatus::Stop);
        }
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

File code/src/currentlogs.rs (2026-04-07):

// This is mini-power current logs module for ESP32-C3-WROOM.
// SPDX-License-Identifier: MIT
// Copyright (c) 2025-2026 Hiroshi Nakajima

use log::*;

pub struct CurrentLog {
    pub voltage: f32,
    pub current: f32,
    pub power: f32,
    pub clock: u128,
    pub battery: f32,
    pub temp: f32,
    pub rpm: u32,
    pub pwm: u32,
}

impl CurrentLog {
    pub fn default() -> Self {
        CurrentLog { 
            voltage: 0.0,
            current: 0.0,
            power: 0.0,
            clock: 0,
            battery: 0.0,
            temp: 0.0,
            rpm: 0,
            pwm: 0,
         }
    }
}


pub struct CurrentRecord {
    rec: Vec<CurrentLog>,
}

#[allow(dead_code)]
impl CurrentRecord {
    pub fn new() -> CurrentRecord {
        CurrentRecord { rec: Vec::new() }
    }

    pub fn record(&mut self, data: CurrentLog)
    {
        self.rec.push(data);
    }

    pub fn dump(&self)
    {
        info!("time,voltage,current,power,battery,temp,rpm,pwm");
        for it in &self.rec {
           info!("{},{},{},{},{},{},{},{}", it.clock, it.voltage, it.current, it.power, it.battery, it.temp, it.rpm, it.pwm);
        } 
    }

    pub fn clear(&mut self)
    {
        self.rec.clear()
    }

    pub fn get_size(&self) -> usize {
        self.rec.len()    
    }

    pub fn get_all_data(&self) -> &Vec<CurrentLog> {
        &self.rec
    }

    pub fn remove_data(&mut self, size : usize){
        let mut num = size;
        if self.rec.len() < size {
            num = self.rec.len();
        }       
        let _ = &self.rec.drain(0..num);
    }

}

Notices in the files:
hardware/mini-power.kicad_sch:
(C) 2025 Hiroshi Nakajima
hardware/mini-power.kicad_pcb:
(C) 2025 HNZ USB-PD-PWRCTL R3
